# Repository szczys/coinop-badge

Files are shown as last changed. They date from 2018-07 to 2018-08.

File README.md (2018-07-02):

# coinop-badge

PCB badge inspired by the classic coin-op game Galaga

https://hackaday.io/project/159302/

# KiCAD Library dependencies

Install the KiCad libraries:
` sudo apt-get install kicad-library

Install the [https://github.com/MacroFab/EDALibraries](MacroFab EDALibraries):
` cd ~/compile
` git clone https://github.com/MacroFab/EDALibraries
` cd /usr/share/kicad/modules 
` sudo ln -s ~/compile/EDALibraries/KiCad/Footprints/* .
` cd /usr/share/kicad/library
` sudo ln -s ~/compile/EDALibraries/KiCad/Schematics/* .

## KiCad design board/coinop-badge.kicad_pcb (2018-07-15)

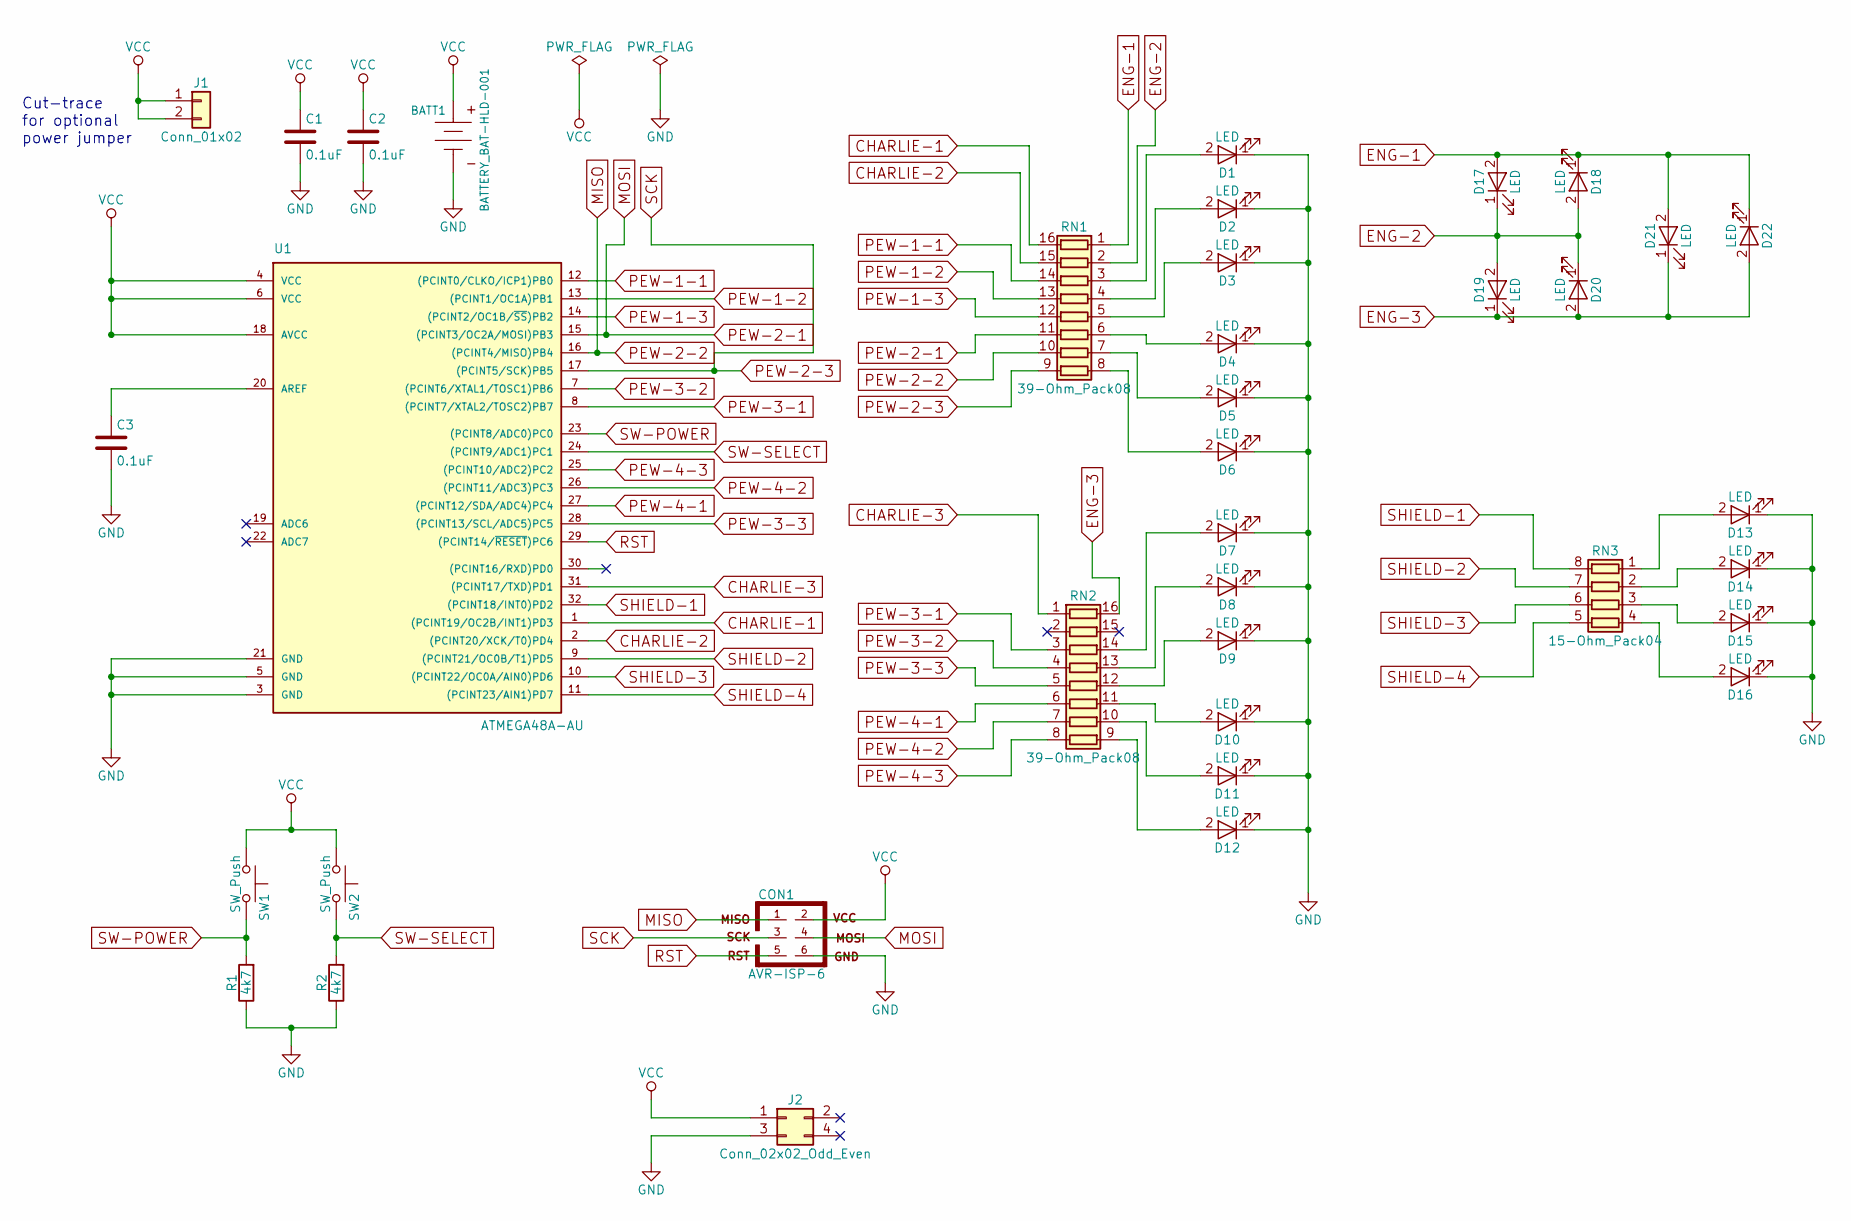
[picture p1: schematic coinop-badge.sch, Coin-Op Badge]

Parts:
BATT1: BATTERY_BAT-HLD-001; MF_Connectors-BAT-HLD-001
C1, C2, C3: 0.1uF; LED_0603
CON1: AVR-ISP-6; SIL_1x06_SMD_Pin_Header
D1, D2, D3, D4, D5, D6, D7, D8, D9, D10, D11, D12, D13, D14, D15, D16, D17, D18, D19, D20, D21, D22: LED; LED_0603
J1: Conn_01x02; SIL_1x02_SMD_Pin_Header
J2: Conn_02x02_Odd_Even; SAO_Pin_Header_Straight_2x02_Pitch2.54mm_SMD
R1, R2: 4k7; R_0603
RN1, RN2: 39-Ohm_Pack08; EXB-2HV390JV
RN3: 15-Ohm_Pack04; EXB-38V150JV
SW1, SW2: SW_Push; Switches-TACT-PTS645
U1: ATMEGA48A-AU; TQFP-32_7x7mm_Pitch0.8mm

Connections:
CHARLIE-1: RN1.16 (R1.2), U1.1 ((PCINT19/OC2B/INT1)PD3)
CHARLIE-2: RN1.15 (R2.2), U1.2 ((PCINT20/XCK/T0)PD4)
CHARLIE-3: RN2.1 (R1.1), U1.31 ((PCINT17/TXD)PD1)
ENG-1: D17.2 (A), D18.1 (K), D21.2 (A), D22.1 (K), RN1.1 (R1.1)
ENG-2: D17.1 (K), D18.2 (A), D19.2 (A), D20.1 (K), RN1.2 (R2.1)
ENG-3: D19.1 (K), D20.2 (A), D21.1 (K), D22.2 (A), RN2.16 (R1.2)
GND: BATT1.NEG_ (NEG), C1.2, C2.2, C3.2, CON1.6, D1.1 (K), D2.1 (K), D3.1 (K), D4.1 (K), D5.1 (K), D6.1 (K), D7.1 (K), D8.1 (K), D9.1 (K), D10.1 (K), D11.1 (K), D12.1 (K), D13.1 (K), D14.1 (K), D15.1 (K), D16.1 (K), J2.3, R1.1, R2.1, U1.3 (GND), U1.5 (GND), U1.21 (GND)
MISO: CON1.1, RN1.10 (R7.2), U1.16 ((PCINT4/MISO)PB4)
MOSI: CON1.4, RN1.11 (R6.2), U1.15 ((PCINT3/OC2A/MOSI)PB3)
unnamed: C3.1, U1.20 (AREF)
unnamed: D1.2 (A), RN1.3 (R3.1)
unnamed: D2.2 (A), RN1.4 (R4.1)
unnamed: D3.2 (A), RN1.5 (R5.1)
unnamed: D4.2 (A), RN1.6 (R6.1)
unnamed: D5.2 (A), RN1.7 (R7.1)
unnamed: D6.2 (A), RN1.8 (R8.1)
unnamed: D7.2 (A), RN2.14 (R3.2)
unnamed: D8.2 (A), RN2.13 (R4.2)
unnamed: D9.2 (A), RN2.12 (R5.2)
unnamed: D10.2 (A), RN2.11 (R6.2)
unnamed: D11.2 (A), RN2.10 (R7.2)
unnamed: D12.2 (A), RN2.9 (R8.2)
unnamed: D13.2 (A), RN3.1 (R1.1)
unnamed: D14.2 (A), RN3.2 (R2.1)
unnamed: D15.2 (A), RN3.3 (R3.1)
unnamed: D16.2 (A), RN3.4 (R4.1)
PEW-1-1: RN1.14 (R3.2), U1.12 ((PCINT0/CLKO/ICP1)PB0)
PEW-1-2: RN1.13 (R4.2), U1.13 ((PCINT1/OC1A)PB1)
PEW-1-3: RN1.12 (R5.2), U1.14 ((PCINT2/OC1B/~SS~)PB2)
PEW-2-3: CON1.3, RN1.9 (R8.2), U1.17 ((PCINT5/SCK)PB5)
PEW-3-1: RN2.3 (R3.1), U1.8 ((PCINT7/XTAL2/TOSC2)PB7)
PEW-3-2: RN2.4 (R4.1), U1.7 ((PCINT6/XTAL1/TOSC1)PB6)
PEW-3-3: RN2.5 (R5.1), U1.28 ((PCINT13/SCL/ADC5)PC5)
PEW-4-1: RN2.6 (R6.1), U1.27 ((PCINT12/SDA/ADC4)PC4)
PEW-4-2: RN2.7 (R7.1), U1.26 ((PCINT11/ADC3)PC3)
PEW-4-3: RN2.8 (R8.1), U1.25 ((PCINT10/ADC2)PC2)
RST: CON1.5, U1.29 ((PCINT14/~RESET~)PC6)
SHIELD-1: RN3.8 (R1.2), U1.32 ((PCINT18/INT0)PD2)
SHIELD-2: RN3.7 (R2.2), U1.9 ((PCINT21/OC0B/T1)PD5)
SHIELD-3: RN3.6 (R3.2), U1.10 ((PCINT22/OC0A/AIN0)PD6)
SHIELD-4: RN3.5 (R4.2), U1.11 ((PCINT23/AIN1)PD7)
SW-POWER: R1.2, SW1.2, U1.23 ((PCINT8/ADC0)PC0)
SW-SELECT: R2.2, SW2.2, U1.24 ((PCINT9/ADC1)PC1)
VCC: BATT1.POS_ (POS), C1.1, C2.1, CON1.2, J1.1, J1.2, J2.1, SW1.1, SW2.1, U1.4 (VCC), U1.6 (VCC), U1.18 (AVCC)

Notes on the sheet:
Cut-trace for optional power jumper

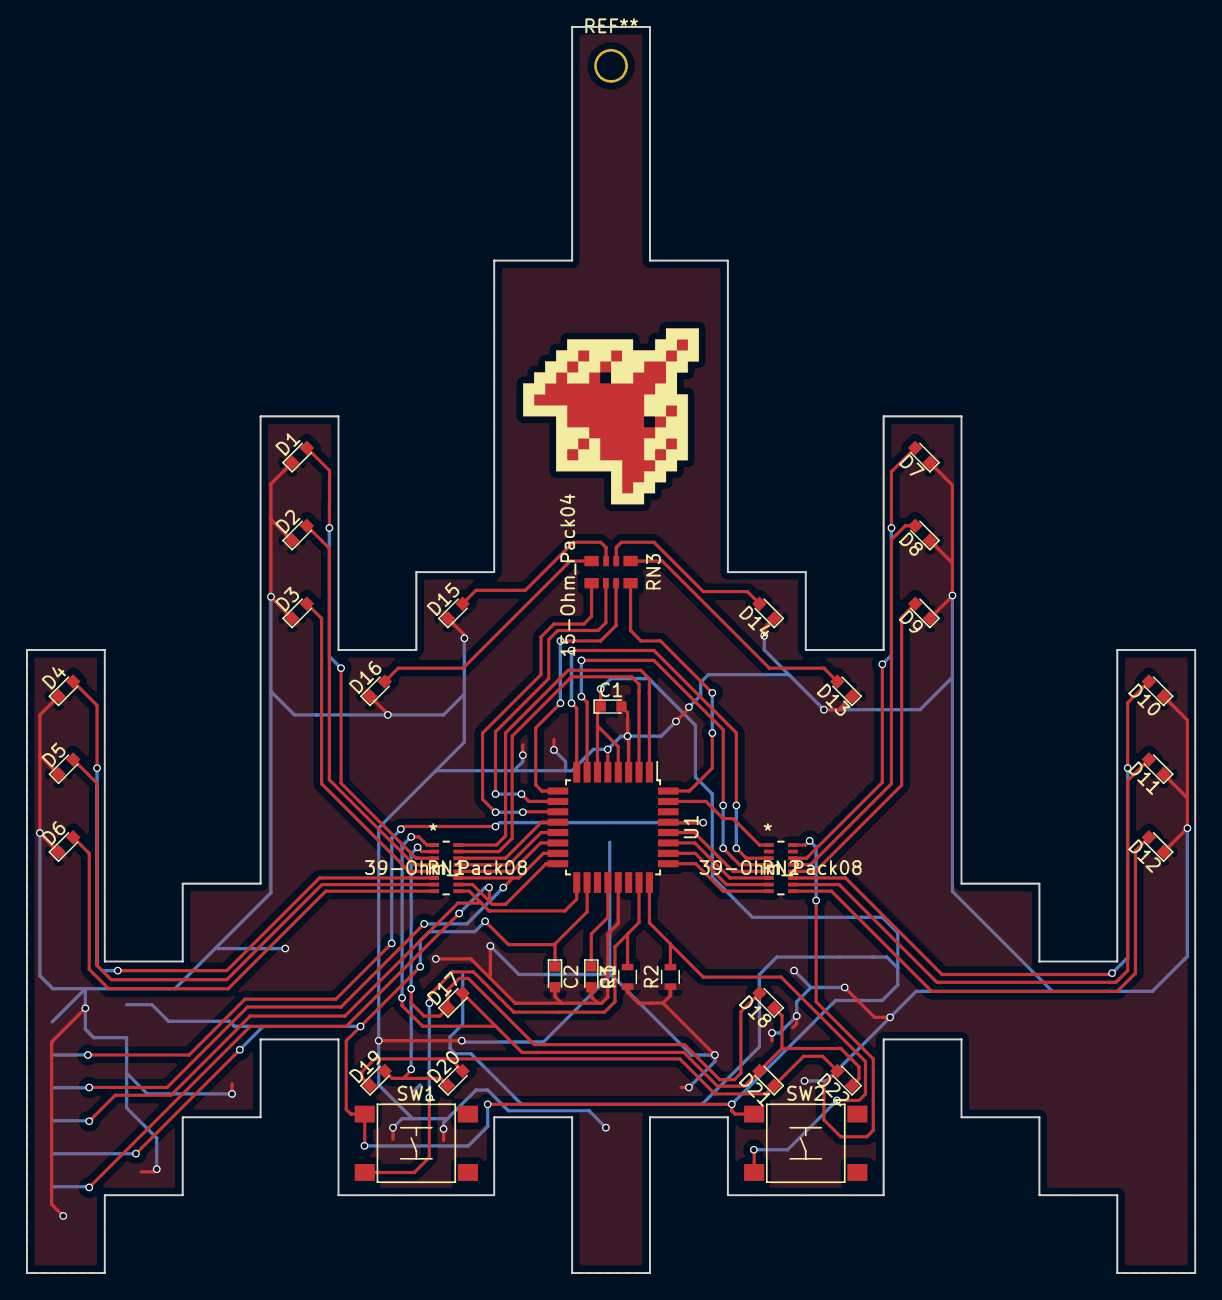
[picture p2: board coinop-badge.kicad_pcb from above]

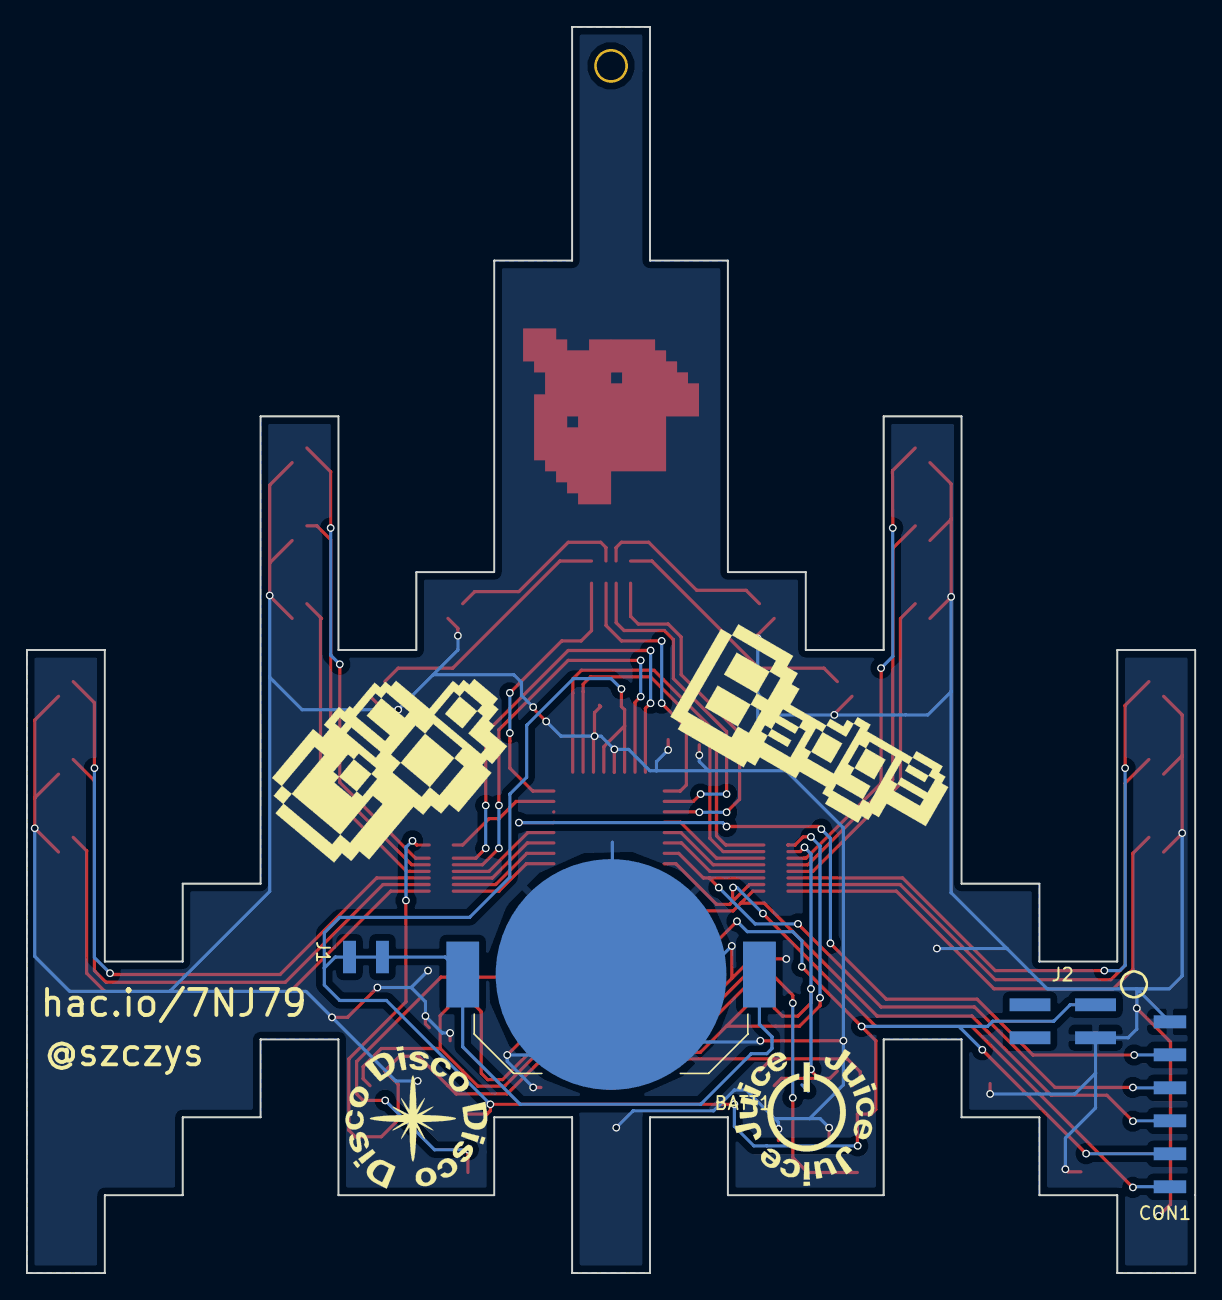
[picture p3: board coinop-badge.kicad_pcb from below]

Board: 2 copper layers, 90.0 x 96.0 mm, 37 parts (4 on the bottom side), 44 nets.

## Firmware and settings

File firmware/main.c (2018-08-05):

#define F_CPU 8000000L
#include <avr/io.h>
#include <avr/interrupt.h>
#include <util/delay.h>
#include <avr/sleep.h>
#include <avr/wdt.h>
#include "debounce.h"

#define FIRMWARE_VERSION    3

#define STATE_NOSTATE       0
#define STATE_CONFIRMSLEEP  1
#define STATE_CONFIRMWAKE   2
#define STATE_ASLEEP        3
#define STATE_POST          4
#define STATE_SWEEP         5
#define STATE_FADE          6
#define STATE_PEW           7
#define STATE_MANUALPEW     8
#define STATE_WAIT          9
#define STATE_SPARKLE       10

#define HIBERNATE           0
#define SNOOZE              1

uint8_t state;

#define PEWLEFTIN1        (1<<PB0)
#define PEWLEFTIN2        (1<<PB1)
#define PEWLEFTIN3        (1<<PB2)
#define PEWLEFTOUT1       (1<<PB3)
#define PEWLEFTOUT2       (1<<PB4)
#define PEWLEFTOUT3       (1<<PB5)
#define PEWRIGHTIN1       (1<<PB7)
#define PEWRIGHTIN2       (1<<PB6)
#define PEWRIGHTIN3       (1<<PC5)
#define PEWRIGHTOUT1      (1<<PC4)
#define PEWRIGHTOUT2      (1<<PC3)
#define PEWRIGHTOUT3      (1<<PC2)

#define SHIELDLEFTOUT     (1<<PD6)
#define SHIELDLEFTIN      (1<<PD7)
#define SHIELDRIGHTOUT    (1<<PD2)
#define SHIELDRIGHTIN     (1<<PD5)

#define CHARLIE1          (1<<PD3)
#define CHARLIE2          (1<<PD4)
#define CHARLIE3          (1<<PD1)

#define OUT_MASK_B        (PEWLEFTIN1 | PEWLEFTIN2 | PEWLEFTIN3 | PEWLEFTOUT1 | PEWLEFTOUT2 | PEWLEFTOUT3 | PEWRIGHTIN1 | PEWRIGHTIN2)
#define OUT_MASK_C        (PEWRIGHTIN3 | PEWRIGHTOUT1 | PEWRIGHTOUT2 | PEWRIGHTOUT3)
#define OUT_MASK_D        (SHIELDLEFTOUT | SHIELDLEFTIN | SHIELDRIGHTIN | SHIELDRIGHTOUT)

//Used to multiplex RED LEDs
#define FADE_RESOLUTION   96
volatile uint8_t bmatrix[FADE_RESOLUTION];
volatile uint8_t cmatrix[FADE_RESOLUTION];
volatile uint8_t dmatrix[FADE_RESOLUTION];
const uint8_t led_order[16] = { PEWLEFTOUT1, PEWLEFTOUT2, PEWLEFTOUT3, \
                                PEWLEFTIN1, PEWLEFTIN2, PEWLEFTIN3, \
                                PEWRIGHTIN1, PEWRIGHTIN2, PEWRIGHTIN3, \
                                PEWRIGHTOUT1, PEWRIGHTOUT2, PEWRIGHTOUT3, \
                                SHIELDLEFTOUT, SHIELDLEFTIN, SHIELDRIGHTIN, SHIELDRIGHTOUT};
const uint8_t scan_order[16] = { 0,1,2,3,4,5,3,4,5,0,1,2,0,2,3,5 };
const uint8_t pwm_distribution[16] = { 0, 8, 4, 12, 1, 9, 5, 13, 2, 10, 6, 14, 3, 7, 11, 15 };
const uint8_t logscale[18] = { 1,2,3,4,5,6,7,10,14, 16, 14, 10, 7, 6, 5, 4, 3, 2 };
const uint8_t sparkle_rando[22] = {18,2,0,14,4,5,3,15,10,13,6,17,11,8,21,9,19,16,12,1,20,7};
const uint8_t sweep0[6] = { 0,3,6,9,6,3 };
const uint8_t sweep1[6] = { 13,12,14,15,14,12 };
const uint8_t sweep2[6] = { 2,5,8,11,8,5 };
const uint8_t sweep3[6] = { 3, 1, 2, 6, 2, 1 };
uint8_t laser_l[6] = { 2,1,0,5,4,3 };
uint8_t laser_r[6] = { 11,10,9,8,7,6 };

#define POST_DELAY          100
#define PULSATE_DELAY       40
#define CHARLIE_SPIN_DELAY  120
#define PEW_BOTH            8
#define PEW_INNER           4
#define PEW_OUTER           16
#define PEW_DELAY           80
#define SPARKLE_DELAY       40
#define HARD_SLEEP_PERIOD   (uint32_t)500*60*90 //90-minutes sleep (badge snoozes rouhgly 1/2 the time so 500 == 1second)

volatile uint8_t charlie_array[6] = { 0, 0, 0, 0, 0, 0 };
const uint8_t charlie_spin_idx[6] = { 1,4,3,2,5,6 };

#define CHARLIE_MASK      (CHARLIE1 | CHARLIE2 | CHARLIE3)
#define CHARLIE_DDR       DDRD
#define CHARLIE_PORT      PORTD

volatile uint32_t ticks; //Used for upcounting milliseconds

struct TrackTime {
  uint8_t counter0, counter1;
  uint32_t wait_until0, wait_until1;
} tt;

uint8_t generic_counter;
uint32_t hard_sleep_time = HARD_SLEEP_PERIOD;
uint32_t charlie_timer = 0;
uint8_t ignore_next_key_short = 0;

/**************************** Function Prototypes *****************************/
//Hardware specific functions
uint32_t get_time(void);
void init_io(void);
void disable_io(void);
void init_timers(void);
void init_pcint(void);
void disable_pcint(void);
void disable_button_int(void);
void enable_button_int(void);
void sleep_my_pretty(uint8_t timed);
void set_led(uint8_t lednum, uint8_t onoff);
void clear_charlie_array(void);
void charlie(uint8_t led_num);
void start_fade(void);
void fade_led(uint8_t lednum, uint8_t dimness);

//LED visualization functions
uint8_t post(struct TrackTime *ptt);
uint8_t pulsate(struct TrackTime *ptt);
void init_pew(uint8_t counter0_value, uint8_t counter1_value);
void laser(uint8_t counter_value, uint8_t laser_led[]);
void laser_turret_servicer(uint8_t * counter, uint32_t * wait_until, uint32_t nexttime, uint8_t laserarray[]);
uint8_t pew(struct TrackTime *ptt);
uint8_t sparkle(struct TrackTime *ptt);
void sweep_helper(uint8_t step, const uint8_t sweep_idx[]);
uint8_t sweep(struct TrackTime *ptt);

//State handling functions
void clean_slate(void);
void advance_state(uint8_t newstate);
void timed_advance(void);
void verify_sleep(uint8_t previous_state);
void dont_wake_early(uint8_t previous_state);
void inc_hard_sleep(void);

/**************************** Hardware specific functions *****************************/

uint32_t get_time(void) {
  //Return the upcounting milliseconds timer (interrupt driven)
  return ticks;
}

void init_io(void) {
  //Set up LED pins
  DDRB |= OUT_MASK_B;
  DDRC |= OUT_MASK_C;
  DDRD |= OUT_MASK_D;

  //Set up Chalieplex pins
  CHARLIE_DDR &= ~(CHARLIE_MASK);

  //Set up button input
  KEY_DDR &= ~KEY_MASK;
}

void all_outputs_low(void) {
  PORTB &= ~(OUT_MASK_B);
  PORTC &= ~(OUT_MASK_C);
  PORTD &= ~(OUT_MASK_D);
}

void disable_io(void) {
  //Will be used for sleep modes

  //Set up LED pins as inputs and disable pull-ups
  DDRB &= ~(OUT_MASK_B);
  DDRC &= ~(OUT_MASK_C);
  DDRD &= ~(OUT_MASK_D);
  all_outputs_low();

  //All charlieplexing pins input (Hi-Z mode)
  CHARLIE_DDR &= ~(CHARLIE_MASK);
  CHARLIE_PORT &= ~(CHARLIE_MASK);

  //Buttons should already be set as inputs without pull-ups
  //they connect to VCC and have external pull-downs
}

void init_timers(void) {
  TCCR0B = 1<<CS01 | 1<<CS00;	//divide by 64
  TIMSK0 = 1<<TOIE0;		//enable overflow interrupt

  TCCR1B = 1<<WGM12 | 1<<CS11 | 1<<CS10;  //CTC mode with prescaler of 64
  OCR1AL = 20; // 6.2 kHz
  //TIMSK1 |= 1<<OCIE1A;
}

void init_pcint(void) {
  PCICR |= (1<<PCIE1);
  PCMSK1 |= (1<<PCINT8);
  PCIFR |= 1<<PCIF1;    //Clear the PCINT flag (might not have been done after last wakeup)
}

void disable_pcint(void) {
  PCICR &= ~(1<<PCIE1);
}

void disable_button_int(void) {
  TIMSK0 &= ~(1<<TOIE0);		//enable overflow interrupt
}

void enable_button_int(void) {
  TIMSK0 |= 1<<TOIE0;		//enable overflow interrupt
}

void sleep_my_pretty(uint8_t timed) {
  cli();                //disable interrupts
  disable_io();         //make sure we're not driving pins while asleep
  init_pcint();         //enable pin-change interrupts to wake from sleep
  if (timed) {
    PCMSK1 |= 1<<PCINT9;  //Only need pcint on KEY1 when snoozing
    wdt_reset();
    MCUSR &= ~(1<<WDRF);
    WDTCSR |= (1<<WDCE | 1<<WDE);
    WDTCSR = (1<<WDIE | 1<<WDP3);
  }
  set_sleep_mode(SLEEP_MODE_PWR_DOWN);  //Set mode for lowest power
  sleep_enable();       //Get ready for sleep
  //sleep_bod_disable();  //Disable brown-out detection for lower power (apparently not for ATmega48
  sei();                //Ensure interrupts are enabled (lest we never wake)
  sleep_cpu();          //Sleep immediately after enabling interrupts so non can fire before sleep
  if (timed) {
    PCMSK1 &= ~(1<<PCINT9); //Only need pcint on KEY1 when snoozing
    MCUSR &= ~(1<<WDRF);
    WDTCSR |= (1<<WDCE | 1<<WDE);
    WDTCSR = 0;
  }
  disable_pcint();      //Don't need pin-change interrupts when awake
  sleep_disable();      //Disable to we're in a known state next time we need to sleep
  init_io();            //Get IO pins ready for wakeful operations
}

void set_led(uint8_t lednum, uint8_t onoff) {
  if (lednum < 8) {
    if (onoff) PORTB |= led_order[lednum];
    else PORTB &= ~led_order[lednum];
  }
  else if (lednum < 12) {
    if (onoff) PORTC |= led_order[lednum];
    else PORTC &= ~led_order[lednum];
  }
  else if (lednum < 16) {
    if (onoff) PORTD |= led_order[lednum];
    else PORTD &= ~led_order[lednum];
  }
  else if (lednum <22) {
    if (onoff) charlie(lednum-15);
    else charlie(0);
  }
}

void clear_charlie_array(void) {
  for (uint8_t i=0; i<6; i++) charlie_array[i] = 0;
}

void charlie(uint8_t led_num) {
  //All pins input (Hi-Z mode)
  CHARLIE_DDR &= ~(CHARLIE_MASK);
  CHARLIE_PORT &= ~(CHARLIE_MASK);
  
  switch(led_num) {
    case 0:
      //Pins already Hi-Z so all off
      return;
    case 1:
      //D17
      CHARLIE_DDR |= CHARLIE1;
      CHARLIE_DDR |= CHARLIE2;
      CHARLIE_PORT |= CHARLIE1;
      break;
    case 2:
      //D18
      CHARLIE_DDR |= CHARLIE1;
      CHARLIE_DDR |= CHARLIE2;
      CHARLIE_PORT |= CHARLIE2;
      break;
    case 3:
      //D19
      CHARLIE_DDR |= CHARLIE2;
      CHARLIE_DDR |= CHARLIE3;
      CHARLIE_PORT |= CHARLIE2;
      break;
    case 4:
      //D20
      CHARLIE_DDR |= CHARLIE2;
      CHARLIE_DDR |= CHARLIE3;
      CHARLIE_PORT |= CHARLIE3;
      break;
    case 5:
      //D21
      CHARLIE_DDR |= CHARLIE1;
      CHARLIE_DDR |= CHARLIE3;
      CHARLIE_PORT |= CHARLIE1;
      break;
    case 6:
      //D22
      CHARLIE_DDR |= CHARLIE1;
      CHARLIE_DDR |= CHARLIE3;
      CHARLIE_PORT |= CHARLIE3;
      break;
  };
}

void start_fade(void) { TIMSK1 |= 1<<OCIE1A; }

void fade_led(uint8_t lednum, uint8_t dimness) {
  volatile uint8_t * dimarray;
  if (lednum < 8) dimarray = bmatrix;
  else if (lednum < 12) dimarray = cmatrix;
  else if (lednum < 16) dimarray = dmatrix;
  else return;

  uint8_t row = scan_order[lednum];
  uint8_t col = led_order[lednum];

  for (uint8_t i=0; i<16; i++) { dimarray[(i*6)+row] &= ~col; } //Clear all set values

  for (uint8_t i=0; i<dimness; i++) {
    dimarray[((pwm_distribution[i]*6)+row)] |= col;
  }
}

/**************************** LED visualization functions *****************************/
uint8_t post(struct TrackTime *ptt) {
  if (get_time() < ptt->wait_until0) return 0;

  ptt->wait_until0 = get_time() + POST_DELAY;
  PORTB &= ~(OUT_MASK_B);
  PORTC &= ~(OUT_MASK_C);
  CHARLIE_DDR &= ~(CHARLIE_MASK);
  CHARLIE_PORT &= ~(OUT_MASK_D | CHARLIE_MASK);

  if (ptt->counter0 > 21) return 1;

  set_led(ptt->counter0, 1);
  ptt->counter0 += 1;
  return 0;
}

uint8_t pulsate(struct TrackTime *ptt) {
  //step_counter is which frame of the animation is next
  //next_step_time needs to be reset so main knows when to next execute this function
  if (get_time() < ptt->wait_until0) return 0;
  else {
    if ((TIMSK1 & 1<<OCIE1A) == 0) {
      start_fade();
      ptt->counter0 = 0;
      clear_charlie_array();
    }
    for (uint8_t i=0; i<16; i++) fade_led(i,logscale[ptt->counter0]);
    if (++(ptt->counter0) >= 18) return 1;
    ptt->wait_until0 = get_time() + PULSATE_DELAY;
  }
  if (get_time() > charlie_timer) {
    static uint8_t charlie_spin = 0;
    charlie_timer = get_time() + CHARLIE_SPIN_DELAY;
    charlie_array[0] = charlie_spin_idx[charlie_spin];
    charlie_array[4] = charlie_spin_idx[charlie_spin+3];
    if (++charlie_spin > 2) charlie_spin = 0;
  }
  return 0;
}

void init_pew(uint8_t counter0_value, uint8_t counter1_value) {
  if (counter0_value > 0) {
    tt.counter0 = counter0_value;
    for (uint8_t i=0; i<6; i++) set_led(i,0);
  }
  if (counter1_value > 0) {
    tt.counter1 = counter1_value;
    for (uint8_t i=6; i<12; i++) set_led(i,0);
  }
}

void laser(uint8_t counter_value, uint8_t laser_led[]) {
  //Little modulo hack allows firing innner/outer lasers at separate times
  switch(counter_value%8) {
    case 0: set_led(laser_led[0],1); break;
    case 7: set_led(laser_led[0],0); set_led(laser_led[1],1); break;
    case 6: set_led(laser_led[1],0); set_led(laser_led[2],1); break;
    case 5: set_led(laser_led[2],0); break;
    case 4: set_led(laser_led[3],1); break;
    case 3: set_led(laser_led[3],0); set_led(laser_led[4],1); break;
    case 2: set_led(laser_led[4],0); set_led(laser_led[5],1); break;
    case 1: set_led(laser_led[5],0); break;
  };
}

void laser_turret_servicer(uint8_t * counter, uint32_t * wait_until, uint32_t nexttime, uint8_t laserarray[]) {
  if (*counter == 12) *counter = 0;
  if (*counter > 0) {
    if (get_time() > *wait_until) {
      *wait_until = nexttime;
      if (*counter == 5) *wait_until += PEW_DELAY;
      laser(*counter,laserarray);
      --(*counter);
    }
  }
}

uint8_t pew(struct TrackTime *ptt) {
  if ((ptt->counter0 == 0) & (ptt->counter1 == 0)) return 1;
  //set up callback timers
  uint32_t next = get_time() + PEW_DELAY;
  laser_turret_servicer(&(ptt->counter0),&(ptt->wait_until0), next, laser_l);
  laser_turret_servicer(&(ptt->counter1),&(ptt->wait_until1), next, laser_r);
  return 0;
}

uint8_t animate_pew(struct TrackTime *ptt) {
  if (get_time() < charlie_timer) return 0;
  switch (generic_counter) {
    case 0:
      init_pew(PEW_BOTH, PEW_BOTH);
      break;
    case 1:
      if (pew(ptt) == 0) return 0;
      break;
    case 2:
      init_pew(PEW_OUTER,0);
      break;
    case 3:
      if (pew(ptt) == 0) return 0;
      break;
    case 4:
      init_pew(PEW_OUTER,0);
      break;
    case 5:
      if (pew(ptt) == 0) return 0;
      break;
    case 6:
      init_pew(0,PEW_INNER);
      break;
    case 7:
      if (pew(ptt) == 0) return 0;
      break;
    case 8:
      init_pew(0,PEW_INNER);
      break;
    case 9:
      if (pew(ptt) == 0) return 0;
      break;
    case 10:
      init_pew(0,PEW_OUTER);
      break;
    case 11:
      if (pew(ptt) == 0) return 0;
      break;
    case 12:
      init_pew(0,PEW_OUTER);
      break;
    case 13:
      if (pew(ptt) == 0) return 0;
      break;
    case 14:
      init_pew(PEW_INNER,0);
      break;
    case 15:
      if (pew(ptt) == 0) return 0;
      break;
    case 16:
      init_pew(PEW_INNER,0);
      break;
    case 17:
      if (pew(ptt) == 0) return 0;
      break;
    case 18:
      fade_led(12,16);
      fade_led(14,16);
      charlie_timer = get_time() + 200;
      start_fade();
      break;
    case 19:
      fade_led(13,16);
      fade_led(15,16);
      charlie_timer = get_time() + 200;
      break;
    case 20:
      charlie_array[0] = 1;
      charlie_array[1] = 2;
      charlie_timer = get_time() + 200;
      break;
    case 21:
      charlie_array[2] = 4;
      charlie_array[3] = 5;
      charlie_timer = get_time() + 200;
      break;
    case 22:
      charlie_array[4] = 3;
      charlie_array[5] = 6;
      charlie_timer = get_time() + 2000;
      break;
    default:
      return 1;
      break;
  };
  ++generic_counter;
  return 0;  
}

uint8_t sparkle(struct TrackTime *ptt) {
  if (get_time() < ptt->wait_until0) return 0;
  ptt->wait_until0 = get_time() + SPARKLE_DELAY;

  if (ptt->counter0 > 0) set_led(sparkle_rando[ptt->counter0-1], 0);
  if (ptt->counter0 < 22) set_led(sparkle_rando[ptt->counter0], 1);
  else return 1;
  ptt->counter0 += 1;
  return 0;
}


void sweep_helper(uint8_t step, const uint8_t sweep_idx[]) {
    fade_led(sweep_idx[((6+step)-1)%6],0);
    fade_led(sweep_idx[step%6],16);
}

uint8_t sweep(struct TrackTime *ptt) {
  //0,3,6,9,6,3
  if (get_time() > ptt->wait_until0) {
    ptt->wait_until0 = get_time() + 120;

    sweep_helper(ptt->counter0, sweep0);
    sweep_helper(ptt->counter0, sweep1);
    sweep_helper(ptt->counter0, sweep2);

    charlie_array[0] = sweep3[ptt->counter0%6];
    if (++(ptt->counter0) > 55) return 1;
  } 
  return 0;
}

/**************************** State handling functions *****************************/
void clean_slate(void) {
  //Set all IO back to initialization
  TIMSK1 &= ~(1<<OCIE1A); //Stop the LED scanning timer
  //Set all direct drive LEDs to off
  PORTB &= ~OUT_MASK_B;
  PORTC &= ~OUT_MASK_C;
  PORTD &= ~OUT_MASK_D;
  //Shut down Charlieplex
  charlie(0);
  clear_charlie_array();
  charlie_timer = 0;
  generic_counter = 0;
  //Clear all fade values
  for (uint8_t i=0; i<FADE_RESOLUTION; i++) {
    bmatrix[i] = 0;
    cmatrix[i] = 0;
    dmatrix[i] = 0;
  }
  //Reset counters and wait times
  tt.wait_until0 = 0;
  tt.wait_until1 = 0;
  tt.counter0 = 0;
  tt.counter1 = 0;
}

void advance_state(uint8_t newstate) {
  // If newstate == 0 just increment the state
  clean_slate();
  
  if (newstate) state = newstate;
  else ++state;
  if (state > STATE_SPARKLE) state = STATE_POST;
  if (get_time() > hard_sleep_time) state=STATE_ASLEEP; //Hibernate if no buttons pushed in a long time
  
  switch(state) {
    case STATE_NOSTATE:
      break;
    case STATE_CONFIRMSLEEP:
      fade_led(0,16);
      fade_led(3,16);
      fade_led(6,16);
      fade_led(9,16);
      start_fade();
      break;
    case STATE_POST:
      break;
    case STATE_SWEEP:
      start_fade();
      break;
    case STATE_FADE:
      start_fade();
      break;
    case STATE_PEW:      
      break;
    case STATE_MANUALPEW:
      break;
    case STATE_WAIT:
        tt.wait_until0 = get_time() + 4000;
        break;
    case STATE_SPARKLE:
      break;   
  };
}

void timed_advance(void) {
  sleep_my_pretty(SNOOZE);
  advance_state(0);
}

void verify_sleep(uint8_t previous_state) {
  while(1) {
    if(get_key_short(KEY0)) {
      advance_state(previous_state);
      return;
    }
    if(get_key_rpt(KEY0)) {
      if (tt.counter0 > 2) { 
        fade_led(0, 0);
        disable_button_int();
        while(KEY_PIN & KEY0) { ;; } //Wait for key release
        enable_button_int();
        advance_state(STATE_ASLEEP);
        return;
      }
      else {
        fade_led((3-tt.counter0)*3,0);
        ++(tt.counter0);
      }
    }
  }
}

void dont_wake_early(uint8_t previous_state) {
  start_fade();
  sleep_my_pretty(HIBERNATE);
  tt.counter0 = 0;
  fade_led(tt.counter0, 16);
  start_fade();
  uint32_t loopbreaker = 0; //Guards for false button detections
  //1600000 is about 4x as long as a wake should take, if button not repeating
  //and button not released, go back to sleep
  while(++loopbreaker < 1600000) {
    if(get_key_rpt(KEY0)) {
      if (tt.counter0 > 2) {
        fade_led(9,16);
        disable_button_int();
        while(KEY_PIN & KEY0) { ;; } //wait for key release
        enable_button_int();
        inc_hard_sleep();
        advance_state(previous_state);
        ignore_next_key_short |= KEY0;
        return;
      }
      else {
        fade_led(tt.counter0*3,16);
        ++(tt.counter0);
      }
    }
    if(get_key_short(KEY0)) {
      break;
    }
  }
  advance_state(STATE_ASLEEP);
  return;
}

void inc_hard_sleep(void) { hard_sleep_time = get_time() + HARD_SLEEP_PERIOD; }

/**************************** Main program function *****************************/
int main(void)
{
  ticks = 0;
  state = STATE_POST;

  init_io();
  uint8_t left_laser_tracker = 0;
  uint8_t right_laser_tracker = 0;
  uint8_t previous_state = STATE_FADE;
  
  advance_state(STATE_POST);  //This will initialize the global variables too

  init_timers();
  sei();

  for (uint8_t i=0; i<16; i++) fade_led(i,16);

  while(1)
  {
    switch(state) {
      case STATE_NOSTATE:
        break;
      case STATE_CONFIRMSLEEP:
        verify_sleep(previous_state);
        break;
      case STATE_ASLEEP:
        dont_wake_early(previous_state);
        break;
      case STATE_POST:         
          if (post(&tt)) timed_advance();
        break;
      case STATE_SWEEP:
        if (sweep(&tt)) timed_advance();
        break;
      case STATE_FADE:
        if (pulsate(&tt)) {
          if (++tt.counter1 > 5) timed_advance();
          else tt.counter0 = 0;
        }
        break;
      case STATE_PEW:
        if (animate_pew(&tt)) advance_state(0);
        break;
      case STATE_MANUALPEW:
        if (pew(&tt)) advance_state(0);
        break;
      case STATE_WAIT:
        if (get_time() > tt.wait_until0) advance_state(0);
        break;
      case STATE_SPARKLE:
        if (sparkle(&tt)) {
          if (++(tt.counter1) > 5) timed_advance();
          else tt.counter0 = 0;
        }
        break;
    };
    
    if ((state != STATE_ASLEEP) && (state != STATE_CONFIRMSLEEP)) {
      if(get_key_short(KEY1)) {
        if (ignore_next_key_short & KEY1) { ignore_next_key_short &= ~KEY1; }
        else {
          advance_state(STATE_MANUALPEW);
          if (right_laser_tracker < 2) init_pew(0,PEW_INNER);
          else init_pew(0,PEW_OUTER);
          if (++right_laser_tracker > 3) right_laser_tracker = 0;
          inc_hard_sleep();
        } 
      }
      if(get_key_rpt(KEY1)) {
        advance_state(0);
        ignore_next_key_short |= KEY1;
        inc_hard_sleep();
      }
    }

    if(get_key_short(KEY0)) {
      if(ignore_next_key_short & KEY0) { ignore_next_key_short &= ~KEY0; }
      else {
        advance_state(STATE_MANUALPEW);
        if (left_laser_tracker < 2) init_pew(PEW_INNER,0);
        else init_pew(PEW_OUTER,0);
        if (++left_laser_tracker > 3) left_laser_tracker = 0;
        inc_hard_sleep();
      }
    }
    if(get_key_rpt(KEY0)) {
      if ((state != STATE_CONFIRMSLEEP) && (state != STATE_ASLEEP)) previous_state = state;
      advance_state(STATE_CONFIRMSLEEP);
      inc_hard_sleep();
    }
  }
}

/**************************** Interrupt servicing functions *****************************/
ISR(PCINT1_vect) {
  //Don't actually need an ISR to wake from sleep
}

ISR(WDT_vect) {
  //Don't actually need an ISR to wake from sleep
}


ISR(TIMER0_OVF_vect)           // every 1ms
{
  ++ticks;

  TCNT0 = (unsigned char)(signed short)-(((F_CPU / 64) * .001) + 0.5);   // preload for 1ms

  if (((uint8_t)ticks%10) == 0) {
    key_isr();
  }
}

ISR(TIMER1_COMPA_vect) {
  static uint8_t dimness = 0;
  all_outputs_low();
  PORTB |= bmatrix[dimness];
  PORTC |= cmatrix[dimness];
  PORTD |= dmatrix[dimness];

  static uint8_t c = 0;
  charlie(charlie_array[c]);
  if (++c>5) c=0;

  if (++dimness >= FADE_RESOLUTION) dimness = 0;
  
}

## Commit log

2018-06-29 initial commit -- board v1.0
    [coinop-badge.kicad_pcb, coinop-badge.sch]
2018-07-02 Added schematic frame info Removed incorrect 3D model from edited footprint
    [coinop-badge.kicad_pcb, coinop-badge.sch]
2018-07-03 Power on self test code (untested)
2018-07-04 Removed erroneous connection left over from larger charlieplex array
    [coinop-badge.kicad_pcb, coinop-badge.sch]
2018-07-04 Added debounce FIXME: debouncing the button for sleep requires double click before second sleep mode cycle is entered. Bizarre
    [main.c]
2018-07-04 Debounced buttons are now working to enter sleep mode
2018-07-04 Moved Timer0 to 1ms to use as non-blocking delay value
2018-07-04 Made POST nonblocking FIXME: POST stops with last charlieplexed LED still lit
    [main.c]
2018-07-04 Fixed charliexplex handling in post()
    [main.c]
2018-07-05 Empty ISR is required; without it there's a jumpt to reset
    [main.c]
2018-07-07 Fixed: PCINT flag wasn't being cleared after wake Fixed: Maping error in POST Added: Charlieplexing via TIMER1 (commented out the interrupt enable though) Updated: Clock speed and chip value for ATme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
    [main.c]
2018-07-07 Fixed routing mistake on buttons. Board now at v2
    [coinop-badge.kicad_pcb]
2018-07-07 Added 4 level PWM
2018-07-07 Addded 16 stages of fading (multiplexed 6 was so 96 steps)
2018-07-08 Buttons fire lasers
2018-07-08 Added disco-button hold for state increment
2018-07-08 Abstracted button handling into separate file
2018-07-09 Fixed overflow in sparkle()
    [main.c]
2018-07-09 Added low-power sleep between visualizations (WDT or PCINT to wake)
2018-07-09 Added ability for buttons to fire lasers one at a time
2018-07-10 Modified support for manual lasers
2018-07-10 Woking through hairy button reads (avoiding spurious presses when waking or repeating)
    [main.c]
2018-07-10 Added power down sequence FIXME: Power keypress is happening immediately after wakeup
    [main.c]
2018-07-10 Fixed spurious button presses in power down sequence
    [main.c]
2018-07-14 Working out button handling
2018-07-15 Button behavior now stable
2018-07-15 Added 90-minute hard sleep timer if no buttons are pushed
2018-07-15 Fixed button routing error Added SAO header (wired as add-on, not host) Added button labels
    [coinop-badge.kicad_pcb, coinop-badge.sch]
2018-07-15 Abstracted timers and step counters into a struct
2018-07-15 Cleaning up prototypes
2018-07-15 Saved some space by combining laser functions
2018-07-15 Fixed missing dereference operator
    [main.c]
2018-07-16 Fixed pew animation ending
    [main.c]
2018-07-20 Added (commented out) line with fuse burning command. Use with caution
2018-07-31 Ignore disco button during power up and power down confirmations
2018-08-05 Added way to break loop in wake cheack (prevent false readings that wake the uC)
    [main.c]

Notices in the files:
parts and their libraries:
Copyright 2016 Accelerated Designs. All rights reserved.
